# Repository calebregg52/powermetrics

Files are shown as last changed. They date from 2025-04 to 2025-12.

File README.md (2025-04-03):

# ⚡ Powermetrics

A real-time voltage and current monitoring web application powered by an ESP32 and dual I2C ADCs. This dashboard visualizes voltage and current data, allows WiFi and channel configuration, and logs data via WebSocket.

## 📦 Project Overview

This project includes:
- **ESP32 Firmware** (`main.cpp`) that reads ADC values and hosts a web server/websocket.
- **Web Interface** (`index.html`, `style.css`, `script.js`) for live monitoring, configuration, and data visualization.
- **WebSocket Communication** for real-time data updates.
- **Chart.js**-powered graphs.
- **Dark mode toggle** and **trigger-based recording**.

## 🚀 Getting Started

### 📁 File Structure

```
powermetrics/
├── main.cpp            # ESP32 Firmware (Arduino)
├── index.html          # Frontend HTML
├── style.css           # Custom styling
├── script.js           # Chart logic & WebSocket handling
├── logo.png            # Optional logo for branding
```

## 🔌 Hardware Setup

- **ESP32 Development Board**
- **2x MCP3426 ADCs** over I2C
- **Wiring**:
  - `SDA` → GPIO 21
  - `SCL` → GPIO 22
- **Voltage Divider** circuit for proper scaling
- **Current Sensors**

## 🧠 ESP32 Firmware (main.cpp)

The firmware performs:
- Periodic reads of ADC channels
- JSON formatting of readings
- WebSocket broadcasting to frontend
- WiFiManager setup for captive portal fallback
- Optional support for WPA2-Enterprise WiFi

### 🔧 Configure WiFi on First Boot

```cpp
WiFiManager wifiManager;
wifiManager.autoConnect("ESP32-Setup");
```

### 📡 WebSocket Broadcast Snippet

```cpp
String jsonResponse = buildJsonResponse(csvLine);
webSocket.broadcastTXT(jsonResponse);
```

## 🖥️ Frontend Features

### 🌐 Live Dashboard

Powered by Bootstrap + Chart.js:

```html
<canvas id="voltageGraph"></canvas>
<canvas id="currentGraph"></canvas>
```

### 📊 Real-Time Charts

```javascript
new Chart(ctx, {
  type: 'line',
  data: { labels, datasets },
  options: getChartOptions()
});
```

### 💡 Dark Mode Toggle

```javascript
document.getElementById('darkModeToggle').addEventListener('change', () => {
  document.body.classList.toggle('dark-mode');
});
```

### 📡 WebSocket Live Feed

```javascript
const socket = new WebSocket(`ws://${window.location.hostname}:81/`);
socket.onmessage = (event) => {
  const data = JSON.parse(event.data);
  // Update gauges and charts
};
```

## ⚙️ Channel & WiFi Configuration

### ADC Channel Toggle

```javascript
fetch('/get-channels')
  .then(response => response.json())
  .then(channels => {
    // Dynamically render channel switches
  });
```

### WPA2-Enterprise Support

```json
{
  "useEnterprise": true,
  "enterpriseSsid": "EDU-SSID",
  "enterpriseUsername": "user@school.edu",
  "enterprisePassword": "password123"
}
```

## 📁 Data Logging

- CSV logs are saved to SPIFFS (`/adc_log.csv`)
- Download via browser with the **Download Log** button

```cpp
logToCsv(csvLine);
```

## 🛠️ Build & Flash (Arduino / PlatformIO)

### 🧰 Required Libraries
- `WiFiManager`
- `WebSocketsServer`
- `SPIFFS`
- `Wire`

### 🧪 PlatformIO Build Command

```ini
[env:esp32dev]
platform = espressif32
board = esp32dev
framework = arduino
lib_deps =
    bblanchon/ArduinoJson
    tzapu/WiFiManager
```
## 👨‍💻 Authors

- Caleb Regg  
- Cade Schapel  
- Logan Howard

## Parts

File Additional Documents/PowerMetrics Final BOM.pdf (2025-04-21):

Item # | Price | Sourced From | Quantity | Manufacturer | Mfg Part # | Description / Value
1 | $17.24 | Amazon | 3 | Espressif Systems | ESP32 | ESP-WROOM-32 ESP32 ESP-32S Development Board 2.4 GHz Dual-Mode WiFi + Bluetooth Dual Microcontroller Processor Integrated with Antenna RF AMP Filter AP STA Compatible with Arduino IDE (3PCS)
2 | $11.41 | DigiKey | 1 | Murata Power Solutions | 811-1448-5-ND | DC DC Converter +/- 5V 1 W
3 | $2.88 | DigiKey | 10 | Texas Instruments | 296-1391-5-ND | IC OPAMP GP 4 CIRCUIT 14DIP
4 | $8.32 | DigiKey | 2 | Ohmite | HS10R1J-ND | RES CHAS MNT 0.1 OHM 5% 10W
5 | $7.54 | Amazon | 1 | AEDIKO | AEDIKO | AEDIKO 5pcs 18650 Lithium Li-ion Battery Charger Module + 5pcs 18650 battery Holder for 18650 Lithium Battery Fast Charging Boost Mobile Power Protection PCB Board
6 | $21.21 | Mouser | 2 | Maruta Power Solutions | NMA0505SC | 2W 5-5V SIP Dual DC/DC Isolated DC/DC Converters - Through Hole
7 | $22.42 | JLCPCB | 5 | JLCPCB | | 2-layer Bare Printed Circuit Board
8 | $9.26 | DigiKey | 2 | Microchip Technology | MCP3428-E/SL | IC ADC 16BIT SIGMA-DELTA 14SOIC
9 | $8.32 | DigiKey | 2 | Analog Devices Inc | LT6106CS5#TRPBFCT-ND | IC CURR SENSE 1 CIRCUIT TSOT23-5
10 | $19.29 | Amazon | 1 | MakerFocus | | 4pcs 3.7V Lithium Rechargeable Battery JST1.25 Connector 2pin, 952540 3.7V 1000mAh Battery withProtection Board and Insulated Rubber Tape Compatible with ESP32 Development Board
11 | $8.49 | Amazon | 1 | | | 20Pcs Test Hooks Clips Multimeter Accessories Colorful Large Spring Hook Clip Test Grabber Probe for ElectronicComponents Testing
12 | $6.74 | Amazon | 1 | Nilight | 90013L | Nilight 90013L 12PCS Round Toggle LED Switch 12V Car Truck Rocker On-Off Control Blue Green Yellow Red
13 | $9.64 | Amazon | 1 | | | 60 Values 0805 SMD Resistor Kit, 1500PCS 0 Ohm -10M Ohm 1/8W SMD Chip Resistors Kit for DIY and Experiments (60Values x 25pcs, from 0 to 10M ohm)
14 | $1.60 | DigiKey | 32 | Yageo (VA) | 311-1142-1-ND | CAP CER 0.1UF 16V X7R 0805
15 | $5.12 | DigiKey | 10 | KYOCERA AVX COMPONENTS CORPORATION | 478-TCTP1C106M8RCT-ND | CAP TANT 10UF 20% 16V 0805
16 | $1.73 | DigiKey | 10 | MURATA ELECTRONICS | 490-3906-1-ND | CAP CER 2.2UF 16V X7R 0805
17 | $0.52 | DigiKey | 50 | STACKPOLE ELECTRONICS INC | RMCF0805JT100KCT-ND | RES 100K OHM 5% 1/8W 0805
18 | $0.64 | DigiKey | 50 | STACKPOLE ELECTRONICS INC | RMCF0805FT100KCT-ND | RES 100K OHM 1% 1/8W 0805
19 | $0.63 | DigiKey | 50 | STACKPOLE ELECTRONICS INC | RMCF0805FT680KCT-ND | RES 680K OHM 1% 1/8W 0805
20 | $0.44 | DigiKey | 50 | STACKPOLE ELECTRONICS INC | RMCF0805FT549RCT-ND | RES 549 OHM 1% 1/8W 0805
21 | $0.64 | DigiKey | 50 | STACKPOLE ELECTRONICS INC | RMCF0805FT6K65CT-ND | RES 6.65K OHM 1% 1/8W 0805
22 | $0.63 | DigiKey | 50 | STACKPOLE ELECTRONICS INC | RMCF0805FT2K00CT-ND | RES 2K OHM 1% 1/8W 0805
23 | $0.63 | DigiKey | 50 | STACKPOLE ELECTRONICS INC | 738-RMCF0805FT8K45CT-ND | RES 8.45K OHM 1% 1/8W 0805
24 | $2.84 | DigiKey | 10 | PANASONIC ELECTRONIC COMPONENTS | P0.05BVCT-ND | RES 0.05 OHM 1% 1W 1206
25 | $0.63 | DigiKey | 50 | STACKPOLE ELECTRONICS INC | RMCF0805FT5K11CT-ND | RES 5.11K OHM 1% 1/8W 0805
26 | $0.63 | DigiKey | 50 | STACKPOLE ELECTRONICS INC | 738-RMCF0805FT5K49CT-ND | RES 5.49K OHM 1% 1/8W 0805
27 | $0.44 | DigiKey | 50 | STACKPOLE ELECTRONICS INC | 738-RMCF0805FT1K91CT-ND | RES 1.91K OHM 1% 1/8W 0805
28 | $0.63 | DigiKey | 50 | STACKPOLE ELECTRONICS INC | RMCF0805FT18K2CT-ND | RES 18.2K OHM 1% 1/8W 0805
29 | $0.63 | DigiKey | 50 | STACKPOLE ELECTRONICS INC | RMCF0805FT7K15CT-ND | RES 7.15K OHM 1% 1/8W 0805
30 | $2.93 | DigiKey | 10 | KEYSTONE ELECTRONICS | 36-5001-ND | PC TEST POINT MINIATURE BLACK
31 | $6.56 | DigiKey | 25 | KEYSTONE ELECTRONICS | 36-5003-ND | PC TEST POINT MINIATURE ORANGE
32 | $2.93 | DigiKey | 10 | KEYSTONE ELECTRONICS | 36-5000-ND | PC TEST POINT MINIATURE RED
33 | $23.15 | DigiKey | 5 | MICROCHIP TECHNOLOGY | MCP3428-E/SL-ND | IC ADC 16BIT SIGMA-DELTA 14SOIC
34 | $2.38 | DigiKey | 10 | TEXAS INSTRUMENTS | 296-1391-5-ND | IC OPAMP GP 4 CIRCUIT 14DIP
35 | $1.20 | | | | | Additional Shipping, Sales Tax, and Tariffs
Total | $210.29

### PowerMetric Smart Multimeter Bill of Materials

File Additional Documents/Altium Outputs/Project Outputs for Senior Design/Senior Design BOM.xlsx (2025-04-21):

Quantity | Designator | Manufacturer Part Number | Manufacturer | Comment | SheetNumber | Pricing 1 ($) | Cost ($)
1 | BT1 | B07CXNQ3ZR | Amazon(MakerFocus) | 3.7V Battery | 3 | 1order=17.99 | 4.497
8 | C1, C3, C5, C6, C7, C8, C9, C10 | CC0805KRX7R7BB104 | Yageo | 100nF | 3, 1, 2 | 1=0.1, 10=0.05 | 0.400
2 | C2, C4 | TCTP1C106M8R | Kyocera AVX | TCTP1C106M8R | 3 | 1=0.8, 10=0.512 | 1.600
2 | C11, C12 | GRM21BR71C225KA12L | Murata | 2.2uF | 3 | 1=0.29, 10=0.173 | 0.580
4 | R1, R2, R6, R13 | RMCF0805JT100K | Stackpole Electronics | 301k Ohm | 1 | 1=0.1, 10=0.017 | 0.170 | PN IS INCORRECT
12 | R3, R8, R14, R21, R28, R38, R46, R50, R55, R59, R66, R70 | RMCF0805FT100K | Stackpole Electronics | 100k Ohm | 1, 2 | 1=0.1, 10=0.021 | 0.252
12 | R4, R7, R15, R20, R26, R34, R43, R48, R53, R58, R63, R68 | RMCF0805FT680K | Stackpole Electronics | 680k Ohm | 1, 2 | 1=0.1, 10=0.021 | 0.252
4 | R5, R9, R16, R22 | RMCF0805FT549R | Stackpole Electronics | 549 Ohm | 1 | 1=0.1, 10=0.014 | 0.056
4 | R10, R17, R30, R35 | RMCF0805FT6K65 | Stackpole Electronics | 6.65k Ohm | 1 | 1=0.1, 10=0.021 | 0.084
4 | R11, R18, R31, R36 | RMCF0805FT2K00 | Stackpole Electronics | 2k Ohm | 1 | 1=0.1, 10=0.021 | 0.084
4 | R12, R19, R32, R37 | RMCF0805FT8K45 | Stackpole Electronics | 8.45k Ohm | 1 | 1=0.1, 10=0.021 | 0.084
2 | R23, R40 | ERJ-8CWFR050V | Panasonic | 0.05 Ohm, 1W | 1 | 1=0.52, 10=0.284 | 0.568
10 | R24, R27, R41, R44, R51, R54, R61, R64, R71, R72 | RMCF0805FT5K11 | Stackpole Electronics | 5.11k Ohm | 2, 3 | 1=0.1, 10=0.021 | 0.210
8 | R25, R33, R42, R47, R52, R57, R62, R67 | RMCF0805FT5K49 | Stackpole Electronics | 5.49k Ohm | 2 | 1=0.1, 10=0.021 | 0.168
8 | R29, R39, R45, R49, R56, R60, R65, R69 | RMCF0805FT1K91 | Stackpole Electronics | 1.91k Ohm | 2 | 1=0.1, 10=0.014 | 0.112
8 | R73, R76, R77, R80, R81, R84, R85, R88 | RMCF0805FT18K2 | Stackpole Electronics | 18.2k Ohm | 2 | 1=0.1, 10=0.021 | 0.168
8 | R74, R75, R78, R79, R82, R83, R86, R87 | RMCF0805FT7K15 | Stackpole Electronics | 7.15k Ohm | 2 | 1=0.1, 10=0.021 | 0.168
1 | S1 | B07T1JG6BD | Amazon(Nilight) | Rocker LED Switch | 3 | 1order=6.29 | 0.524
1 | TP1 | 5001 | Keystone | TP (Black) | 3 | 1=0.39, 10=0.293 | 0.390
12 | TP2, TP3, TP4, TP5, TP6, TP7, TP8, TP9, TP10, TP11, TP12, TP13 | 5003 | Keystone | TP (Orange) | 2, 1 | 1=0.39, 10=0.293 | 3.516
4 | TP14, TP15, TP16, TP17 | 5000 | Keystone | TP (Red) | 3 | 1=0.39, 10=0.293 | 1.172
1 | U1 | B08D5ZD528 | Amazon(AITRIP) | ESP32 | 3 | 1order=15.99 | 5.330
1 | U2 | B09X9VMGV4 | Amazon(AEDIKO) | Battery Charger/Booster | 3 | 1order=7.99 | 1.598
1 | U3 | NMA0505SC | Murata | DC DC Converter | 3 | 1=5.08, 10=5.05 | 5.080
2 | U4, U5 | MCP3428-E/SL | Microchip Tech | 4Ch ADC | 3 | 1=4.63 | 9.260
3 | U6, U7, U8 | LM324N | Texas Instruments | 4CH Op-Amp | 1, 2 | 1=0.34, 10=0.238 | 0.714
 |  |  |  |  |  | Total Cost | 37.038

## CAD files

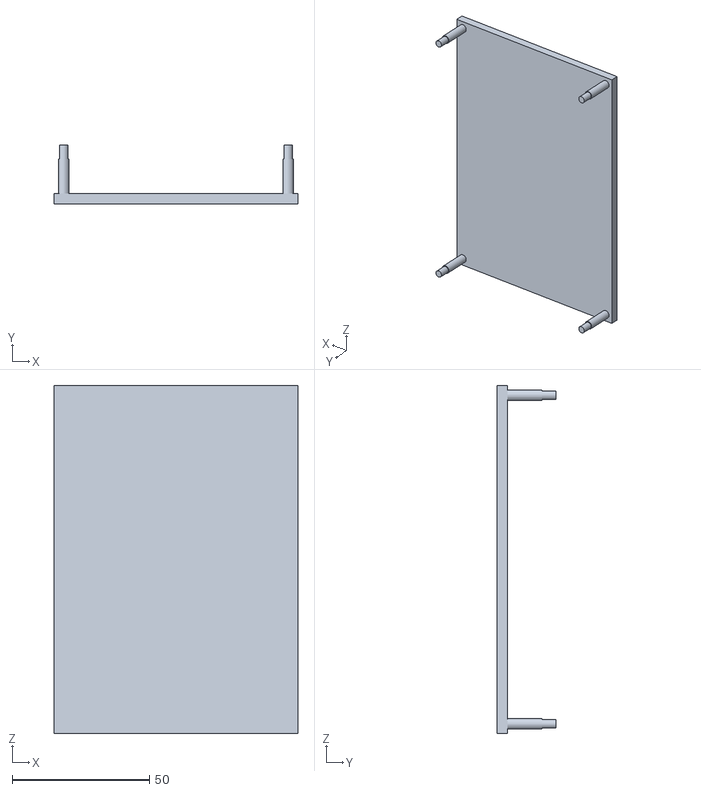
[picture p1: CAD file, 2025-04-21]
Additional Documents/PowerMetrics Stand.stl
88.9 x 21.6 x 127.0

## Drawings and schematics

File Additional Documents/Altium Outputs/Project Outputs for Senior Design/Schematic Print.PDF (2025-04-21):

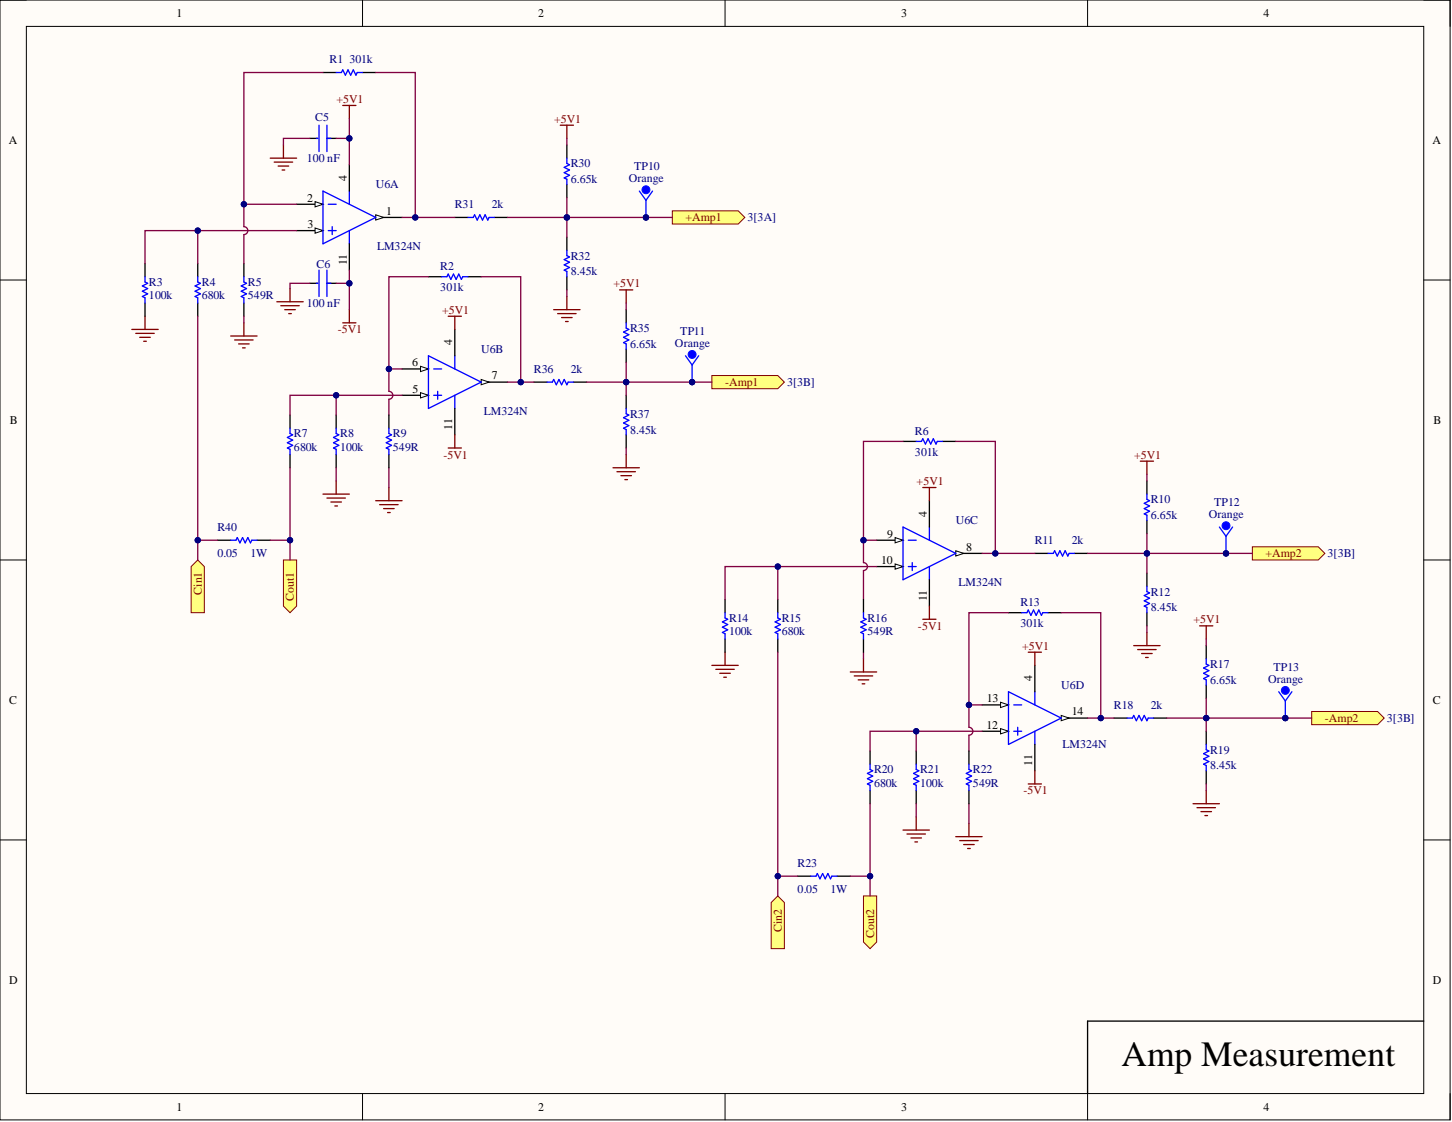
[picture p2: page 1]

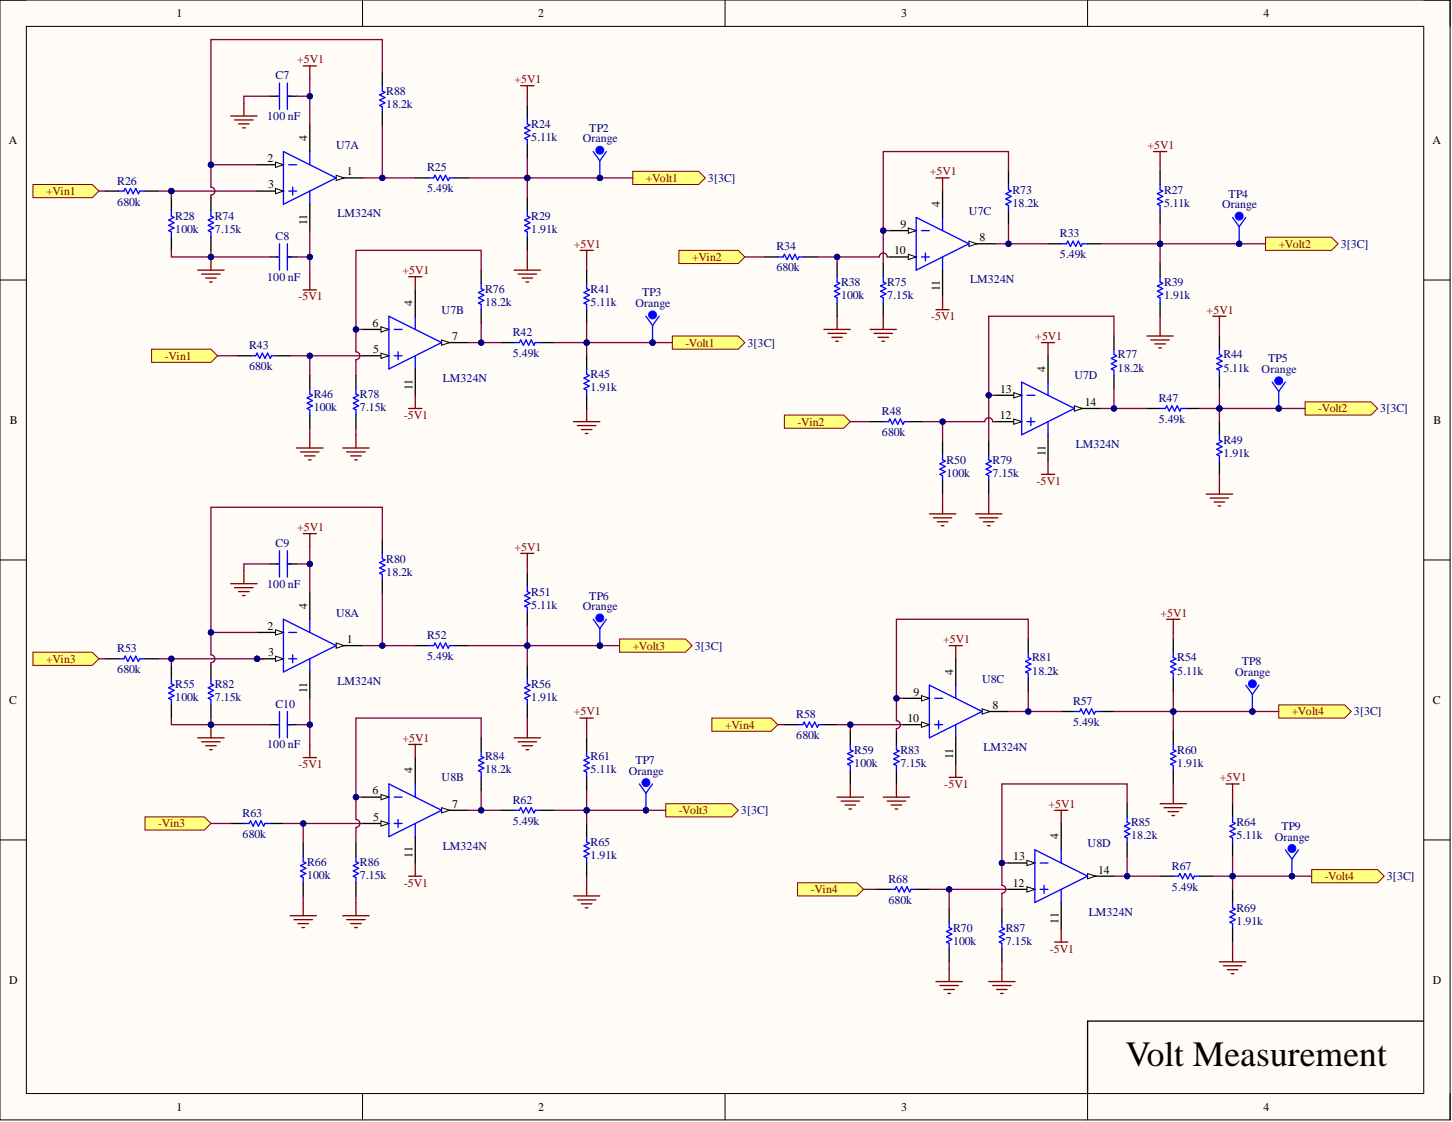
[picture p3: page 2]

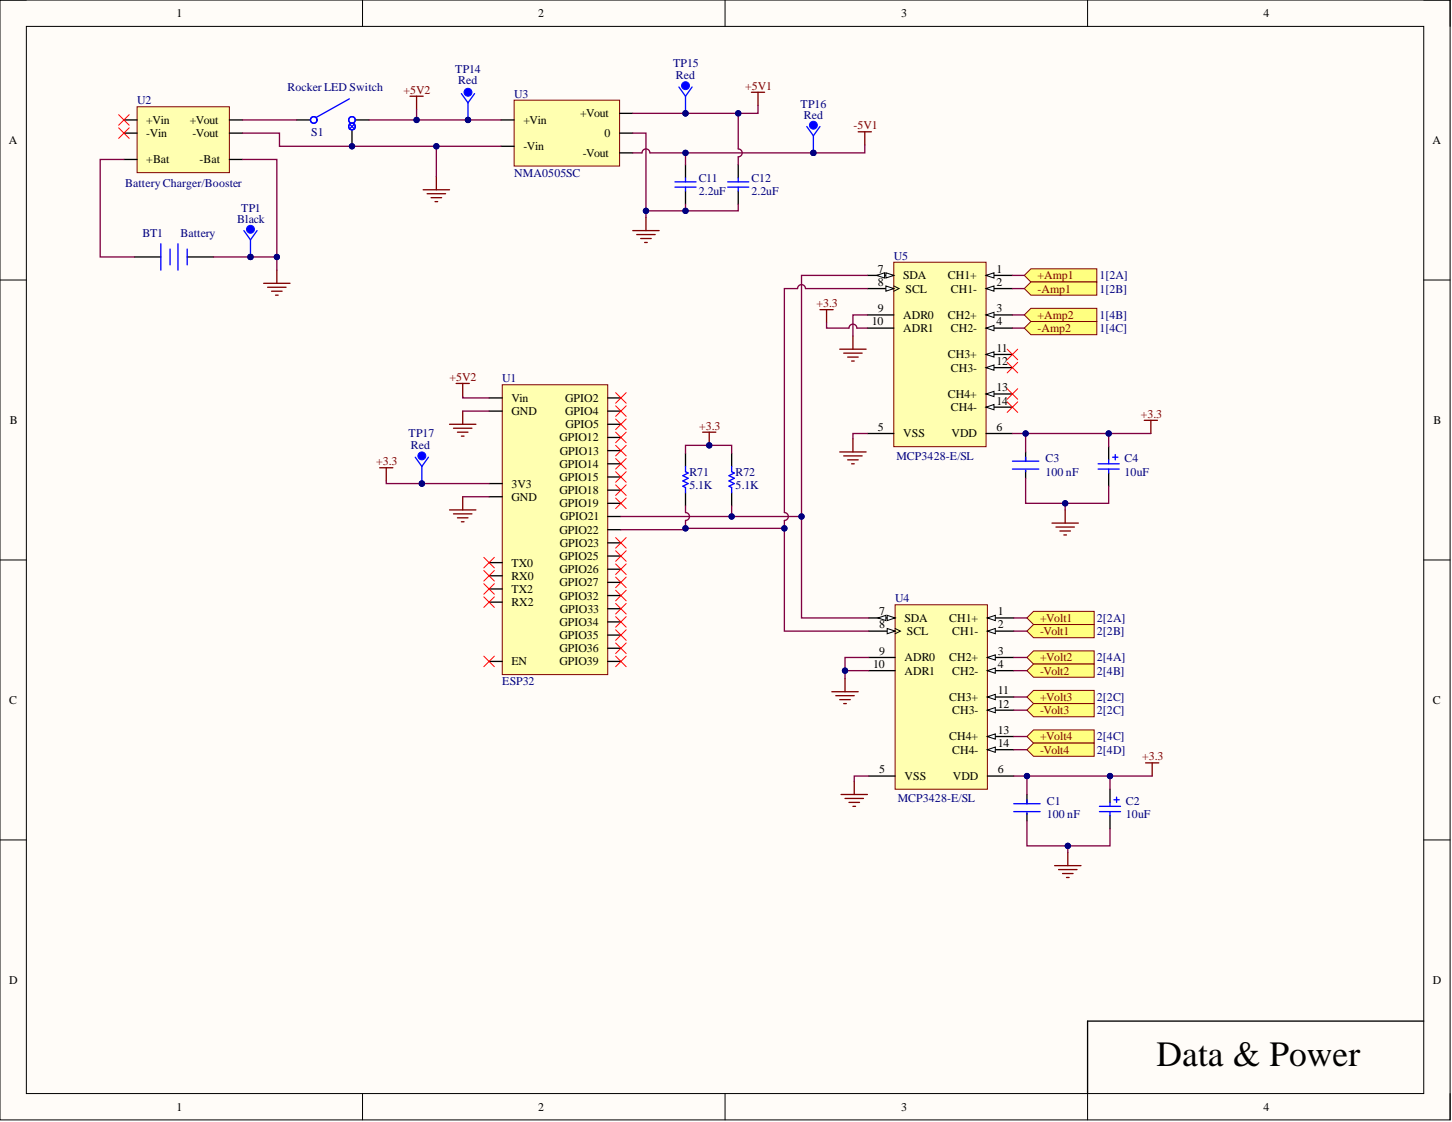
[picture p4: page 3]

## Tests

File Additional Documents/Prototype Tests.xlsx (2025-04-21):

Voltage Circuit |  | Current Circuit
Vin | Vout | Resistance | Current | Vout
18.3 | 2.7 | 6.5 | 0.7692 | 3.22
18.1 | 2.69 | 9.9 | 0.5051 | 2.57
17.8 | 2.68 | 38 | 0.1316 | 1.848
17.4 | 2.65 | 54 | 0.0926 | 1.782
16.9 | 2.63 | 108 | 0.0463 | 1.713
15.9 | 2.58 | 217 | 0.0230 | 1.679
15.3 | 2.55 | 410 | 0.0122 | 1.661
14.6 | 2.51 | 1730 | 0.0029 | 1.648
13.8 | 2.47 | 2110 | 0.0024 | 1.649
12.3 | 2.4 | 2690 | 0.0019 | 1.649
11.6 | 2.36 | 3130 | 0.0016 | 1.648
9.6 | 2.26 | 4680 | 0.0011 | 1.645
8.8 | 2.21 | open | 0.0000 | 1.644
7.1 | 2.13 | 4570 | -0.0011 | 1.642
5.7 | 2.06 | 2360 | -0.0021 | 1.64
4.7 | 2 | 1730 | -0.0029 | 1.639
3.9 | 1.969 | 360 | -0.0139 | 1.623
3.3 | 1.938 | 126 | -0.0397 | 1.589
2.3 | 1.89 | 83 | -0.0602 | 1.556
2.1 | 1.881 | 47 | -0.1064 | 1.487
0 | 1.781 | 33 | -0.1515 | 1.423
-2.1 | 1.68 | 8 | -0.6250 | 0.705
-2.7 | 1.653 | 4.7 | -1.0638 | 0.032
-3.8 | 1.596
-4.4 | 1.563
-5.3 | 1.518
-6.4 | 1.464
-7.3 | 1.417
-8.1 | 1.377
-9.1 | 1.321
-10.3 | 1.265
-11.2 | 1.214
-12.3 | 1.157
-13.5 | 1.098
-14.6 | 1.04
-15.7 | 0.986
-16.2 | 0.958
-16.9 | 0.924
-17.6 | 0.887
-18.4 | 0.848

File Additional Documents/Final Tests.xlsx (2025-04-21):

input | V CH1 | V CH2 | V CH3
14.73 | 1.362 | 1.362 | 1.362
14.21 | 1.313 | 1.314 | 1.314
13.35 | 1.224 | 1.225 | 1.225
12.65 | 1.169 | 1.171 | 1.171 | input | I CH1 | I CH2
12.02 | 1.111 | 1.112 | 1.112 | 0.09 | -0.065 | 0.118
11.75 | 1.086 | 1.088 | 1.088 | 6.4 | -0.049 | 0.105
11.24 | 1.039 | 1.04 | 1.041 | 16.4 | -0.037 | 0.092
10.82 | 1.001 | 1.002 | 1.002 | 22.2 | -0.025 | 0.084
10.45 | 0.966 | 0.968 | 0.968 | 34.4 | -0.007 | 0.072
9.84 | 0.91 | 0.912 | 0.912 | 53.8 | 0.034 | 0.028
9.06 | 0.838 | 0.84 | 0.84 | 70 | 0.056 | 0.01
8.52 | 0.789 | 0.791 | 0.791 | 99.3 | 0.095 | -0.04
8.07 | 0.747 | 0.749 | 0.748 | 124 | 0.154 | -0.077
7.67 | 0.713 | 0.714 | 0.714 | 146.8 | 0.182 | -0.122
7.16 | 0.662 | 0.664 | 0.664 | 185 | 0.246 | -0.186
6.33 | 0.587 | 0.589 | 0.589
6.1 | 0.566 | 0.567 | 0.568
5.62 | 0.521 | 0.523 | 0.523
5.1 | 0.474 | 0.476 | 0.476
4.77 | 0.443 | 0.445 | 0.445
3.52 | 0.327 | 0.33 | 0.33
3.29 | 0.306 | 0.308 | 0.308
2.84 | 0.268 | 0.27 | 0.27
2.15 | 0.201 | 0.203 | 0.203
1.72 | 0.161 | 0.163 | 0.163
1.06 | 0.1 | 0.102 | 0.102
0.8 | 0.076 | 0.078 | 0.078
0.17 | 0.018 | 0.02 | 0.02
0 | 0.018 | 0.02 | 0.02
-0.57 | -0.05 | -0.051 | -0.051
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

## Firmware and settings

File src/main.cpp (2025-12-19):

#include <Wire.h>
#include <Arduino.h>
#include <WiFi.h>
#include <Update.h>
#include <WebServer.h>
#include <DNSServer.h>
#include <SPIFFS.h>
#include <WebSocketsServer.h>
#include <esp_task_wdt.h>
#include <esp_wpa2.h>

// Hardcoded Enterprise WiFi Credentials
const char* ENTERPRISE_SSID = "";
const char* ENTERPRISE_USERNAME = "";
const char* ENTERPRISE_PASSWORD = "";

// Forward declaration
String getTime();

// Constants
const int LED_PIN = 2;
const uint32_t LED_BLINK_INTERVAL_MS = 500;
const uint32_t ADC_READ_INTERVAL_MS = 500;
const uint32_t ADC_CONVERSION_DELAY_MS = 70;
const uint8_t ADC1_ADDRESS = 0x68;  // Voltage ADC (channels 1, 3, 4)
const uint8_t ADC2_ADDRESS = 0x6A;  // Current ADC (channels 1, 2)
const uint8_t SDA_PIN = 21;
const uint8_t SCL_PIN = 22;
const uint32_t WDT_TIMEOUT_S = 10;
const char* LOG_FILE = "/adc_log.csv";

// ADC Channel Configuration
struct AdcChannel {
    uint8_t config;
    uint8_t address;
    const char* name;
    int16_t value;
    bool enabled;
    float multiplier;
    float offset;
};

AdcChannel adcChannels[] = {
    {0b10001000, ADC1_ADDRESS, "voltage_1", 0, true, 10.9925, -0.0904},
    {0b11001000, ADC1_ADDRESS, "voltage_3", 0, true, 10.9984, -0.1045},
    {0b11011000, ADC1_ADDRESS, "voltage_4", 0, true, 10.9979, -0.1046},
    {0b10001000, ADC2_ADDRESS, "current_1", 0, true, 0.61727, 0.06461},
    {0b10101000, ADC2_ADDRESS, "current_2", 0, true, -0.60779, 0.05169},
};

// Global Objects
WebSocketsServer webSocket(81);
WebServer server(80);
bool wifiConnected = false;

// Read a single ADC channel
int16_t readSingleChannel(const AdcChannel& channel) {
    Wire.beginTransmission(channel.address);
    Wire.write(channel.config);
    Wire.endTransmission();
    delay(ADC_CONVERSION_DELAY_MS);
    Wire.requestFrom((uint8_t)channel.address, (uint8_t)2);
    if (Wire.available() == 2) {
        return (Wire.read() << 8) | Wire.read();
    }
    Serial.printf("Error: No data from 0x%02X\n", channel.address);
    return 0;
}

// Update all ADC values
void updateAdcValues() {
    for (auto& channel : adcChannels) {
        if (channel.enabled) {
            channel.value = readSingleChannel(channel);
        } else {
            channel.value = 0;
        }
    }
}

// Build JSON response and return CSV line
String buildJsonResponse(String& csvLine) {
    const float ADC_TO_VOLT = 2.048 / 32768.0;

    float adc_volt_1 = adcChannels[0].value * ADC_TO_VOLT;
    float adc_volt_3 = adcChannels[1].value * ADC_TO_VOLT;
    float adc_volt_4 = adcChannels[2].value * ADC_TO_VOLT;

    float voltage_1 = adcChannels[0].enabled ? 
        (adc_volt_1 <= 0.966 ? (adc_volt_1 * 11.03 - 0.01) : 
         (adc_volt_1 <= 1.389 ? (adc_volt_1 * 11.75 - 0.95) : (adc_volt_1 * 12.05 - 1.65))) : 0.0;
    float voltage_3 = adcChannels[1].enabled ? 
        (adc_volt_3 <= 0.966 ? (adc_volt_3 * 11.03 - 0.01) : 
         (adc_volt_3 <= 1.389 ? (adc_volt_3 * 11.75 - 0.95) : (adc_volt_3 * 12.05 - 1.65))) : 0.0;
    float voltage_4 = adcChannels[2].enabled ? 
        (adc_volt_4 <= 0.966 ? (adc_volt_4 * 11.03 - 0.01) : 
         (adc_volt_4 <= 1.389 ? (adc_volt_4 * 11.75 - 0.95) : (adc_volt_4 * 12.05 - 1.65))) : 0.0;

    float raw_current_1 = adcChannels[3].value * ADC_TO_VOLT;
    float raw_current_2 = adcChannels[4].value * ADC_TO_VOLT;

    float current_1 = adcChannels[3].enabled ? 
        (raw_current_1 * adcChannels[3].multiplier + adcChannels[3].offset) : 0.0;
    float current_2 = adcChannels[4].enabled ? 
        (raw_current_2 * adcChannels[4].multiplier + adcChannels[4].offset) : 0.0;

    char buffer[512];
    snprintf(buffer, sizeof(buffer),
             "{\"time\":\"%s\",\"voltage_1\":%.3f,\"voltage_3\":%.3f,\"voltage_4\":%.3f,"
             "\"current_1\":%.3f,\"current_2\":%.3f,"
             "\"raw_adc_1\":%d,\"raw_adc_3\":%d,\"raw_adc_4\":%d}",
             getTime().c_str(), voltage_1, voltage_3, voltage_4,
             current_1, current_2,
             adcChannels[0].value, adcChannels[1].value, adcChannels[2].value);

    char csvBuffer[128];
    snprintf(csvBuffer, sizeof(csvBuffer),
             "%s,%.3f,%.3f,%.3f,%.3f,%.3f",
             getTime().c_str(), voltage_1, voltage_3, voltage_4, current_1, current_2);
    csvLine = String(csvBuffer);

    return String(buffer);
}

// Log data to CSV file
void logToCsv(const String& csvLine) {
    File file = SPIFFS.open(LOG_FILE, FILE_APPEND);
    if (!file) {
        Serial.println("Failed to open log file for appending");
        return;
    }
    if (file.size() == 0) {
        file.println("time,voltage_1,voltage_3,voltage_4,current_1,current_2");
    }
    file.println(csvLine);
    file.close();
}

// Delete log file
void deleteLogFile() {
    if (SPIFFS.exists(LOG_FILE)) {
        if (SPIFFS.remove(LOG_FILE)) {
            Serial.printf("Deleted %s\n", LOG_FILE);
        } else {
            Serial.printf("Failed to delete %s\n", LOG_FILE);
        }
    }
}

void listFiles() {
    File root = SPIFFS.open("/");
    File file = root.openNextFile();
    while (file) {
        Serial.printf("File: %s Size: %u\n", file.name(), file.size());
        file = root.openNextFile();
    }
}

void displayStorageCapacity() {
    size_t totalBytes = SPIFFS.totalBytes();
    size_t usedBytes = SPIFFS.usedBytes();
    Serial.println("\nSPIFFS Storage Capacity:");
    Serial.printf("Total space: %u bytes\n", totalBytes);
    Serial.printf("Used space: %u bytes\n", usedBytes);
    Serial.printf("Free space: %u bytes\n", totalBytes - usedBytes);
    Serial.printf("Usage: %.1f%%\n", (float)usedBytes / totalBytes * 100.0);
}

void serveFile(const char* path, const char* contentType) {
    File file = SPIFFS.open(path, "r");
    if (!file) {
        Serial.printf("Error: %s not found\n", path);
        server.send(404, "text/plain", "File not found");
        return;
    }
    server.streamFile(file, contentType);
    file.close();
}

String getTime() {
    time_t now = time(nullptr);
    if (now < 100000) return "No NTP sync";
    struct tm timeinfo;
    localtime_r(&now, &timeinfo);
    char buffer[20];
    strftime(buffer, sizeof(buffer), "%Y-%m-%d %H:%M:%S", &timeinfo);
    return String(buffer);
}

// WiFi connection function with hardcoded credentials
bool connectToWiFi() {
    WiFi.disconnect(true);
    WiFi.mode(WIFI_STA);
    Serial.printf("Attempting enterprise WiFi connection to: %s\n", ENTERPRISE_SSID);
    
    esp_wifi_sta_wpa2_ent_set_identity((uint8_t*)ENTERPRISE_USERNAME, strlen(ENTERPRISE_USERNAME));
    esp_wifi_sta_wpa2_ent_set_username((uint8_t*)ENTERPRISE_USERNAME, strlen(ENTERPRISE_USERNAME));
    esp_wifi_sta_wpa2_ent_set_password((uint8_t*)ENTERPRISE_PASSWORD, strlen(ENTERPRISE_PASSWORD));
    esp_wifi_sta_wpa2_ent_enable();
    
    WiFi.begin(ENTERPRISE_SSID);
    
    uint32_t startTime = millis();
    while (WiFi.status() != WL_CONNECTED && millis() - startTime < 10000) {
        delay(500);
        Serial.print(".");
    }
    
    wifiConnected = (WiFi.status() == WL_CONNECTED);
    Serial.printf("\nEnterprise WiFi %s - IP: %s\n",
                 wifiConnected ? "connected" : "failed",
                 wifiConnected ? WiFi.localIP().toString().c_str() : "N/A");
    
    return wifiConnected;
}

void setupWebServer() {
    server.on("/", HTTP_GET, []() { serveFile("/index.html", "text/html"); });
    server.on("/style.css", HTTP_GET, []() { serveFile("/style.css", "text/css"); });
    server.on("/script.js", HTTP_GET, []() { serveFile("/script.js", "application/javascript"); });
    server.on("/logo.png", HTTP_GET, []() { serveFile("/logo.png", "image/png"); });
    
    server.on("/download-log", HTTP_GET, []() {
        if (SPIFFS.exists(LOG_FILE)) {
            File file = SPIFFS.open(LOG_FILE, "r");
            server.streamFile(file, "text/csv");
            file.close();
        } else {
            server.send(404, "text/plain", "Log file not found");
        }
    });

    server.on("/get-channels", HTTP_GET, []() {
        String json = "[";
        for (size_t i = 0; i < sizeof(adcChannels) / sizeof(adcChannels[0]); i++) {
            json += "{\"name\":\"" + String(adcChannels[i].name) + "\",\"enabled\":" + (adcChannels[i].enabled ? "true" : "false") + "}";
            if (i < (sizeof(adcChannels) / sizeof(adcChannels[0]) - 1)) json += ",";
        }
        json += "]";
        server.send(200, "application/json", json);
    });

    server.on("/set-channel", HTTP_POST, []() {
        if (server.hasArg("name") && server.hasArg("enabled")) {
            String name = server.arg("name");
            bool enabled = server.arg("enabled") == "true";
            for (auto& channel : adcChannels) {
                if (name == channel.name) {
                    channel.enabled = enabled;
                    Serial.printf("Channel %s set to %s\n", name.c_str(), enabled ? "enabled" : "disabled");
                    break;
                }
            }
            server.send(200, "text/plain", "OK");
        } else {
            server.send(400, "text/plain", "Invalid request");
        }
    });

    server.begin();
    Serial.printf("HTTP server started at: http://%s\n", WiFi.localIP().toString().c_str());
}

void setupWebSocket() {
    webSocket.begin();
    webSocket.onEvent([](uint8_t num, WStype_t type, uint8_t *payload, size_t length) {
        switch (type) {
            case WStype_CONNECTED:
                Serial.printf("WebSocket[%u] connected from %s\n", num, webSocket.remoteIP(num).toString().c_str());
                break;
            case WStype_DISCONNECTED:
                Serial.printf("WebSocket[%u] disconnected\n", num);
                break;
            case WStype_TEXT:
                Serial.printf("WebSocket[%u] received text: %s\n", num, payload);
                break;
        }
    });
}

void setup() {
    Serial.begin(115200);
    Serial.println("Booting ESP32...");

    Wire.begin(SDA_PIN, SCL_PIN);
    Serial.println("Initializing MCP3426 ADCs...");

    if (!SPIFFS.begin(true)) {
        Serial.println("Failed to mount SPIFFS");
        return;
    }
    Serial.println("SPIFFS mounted successfully");

    if (!connectToWiFi()) {
        Serial.println("Failed to connect to WiFi. Rebooting...");
        delay(5000);
        ESP.restart();
    }

    pinMode(LED_PIN, OUTPUT);

    deleteLogFile();
    listFiles();
    displayStorageCapacity();

    configTime(0, 0, "pool.ntp.org");
    Serial.println("Waiting for NTP sync...");
    delay(5000);
    Serial.printf("Current time: %s\n", getTime().c_str());

    esp_task_wdt_init(WDT_TIMEOUT_S, true);
    esp_task_wdt_add(NULL);

    setupWebSocket();
    setupWebServer();
}

void loop() {
    esp_task_wdt_reset();
    webSocket.loop();
    server.handleClient();

    static uint32_t lastLedToggle = 0;
    static uint32_t lastRead = 0;
    uint32_t now = millis();

    if (wifiConnected && now - lastLedToggle >= LED_BLINK_INTERVAL_MS) {
        digitalWrite(LED_PIN, !digitalRead(LED_PIN));
        lastLedToggle = now;
    }

    if (now - lastRead >= ADC_READ_INTERVAL_MS) {
        updateAdcValues();
        if (webSocket.connectedClients() > 0) {
            String csvLine;
            String jsonResponse = buildJsonResponse(csvLine);
            Serial.printf("Broadcasting: %s\n", jsonResponse.c_str());
            webSocket.broadcastTXT(jsonResponse);
            logToCsv(csvLine);
        }
        lastRead = now;
    }
}

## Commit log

2025-01-22 basic websockets need fixed
    [main.cpp]
2025-01-30 websocket full implementation using basic I2C
2025-04-05 current addition
